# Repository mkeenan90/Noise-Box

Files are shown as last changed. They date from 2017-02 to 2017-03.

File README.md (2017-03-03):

# Noise-Box
## Summary 
I wanted to create the foundation for a noise machine to fulfill many different purposes around my house. My daughter falls asleep to the sound of lullabies; my wife and I use a fan for noise in our room. I'd like to replicate these noises with my own design.

The desired feature set is too large for the first iteration. These desired features are: bluetooth music streaming, selectable recordings of family members reading bedtime books, a daytime music box (coffee shop noise, meditation tracks, podcast player, etc.), Alexa capable, and whatever else I can think up.

In order to achieve these features, the first design focuses on just playing music from an SD card and a bunch of buttons for user input.

## Design Specification
### Software
Eagle CAD

##Schematic
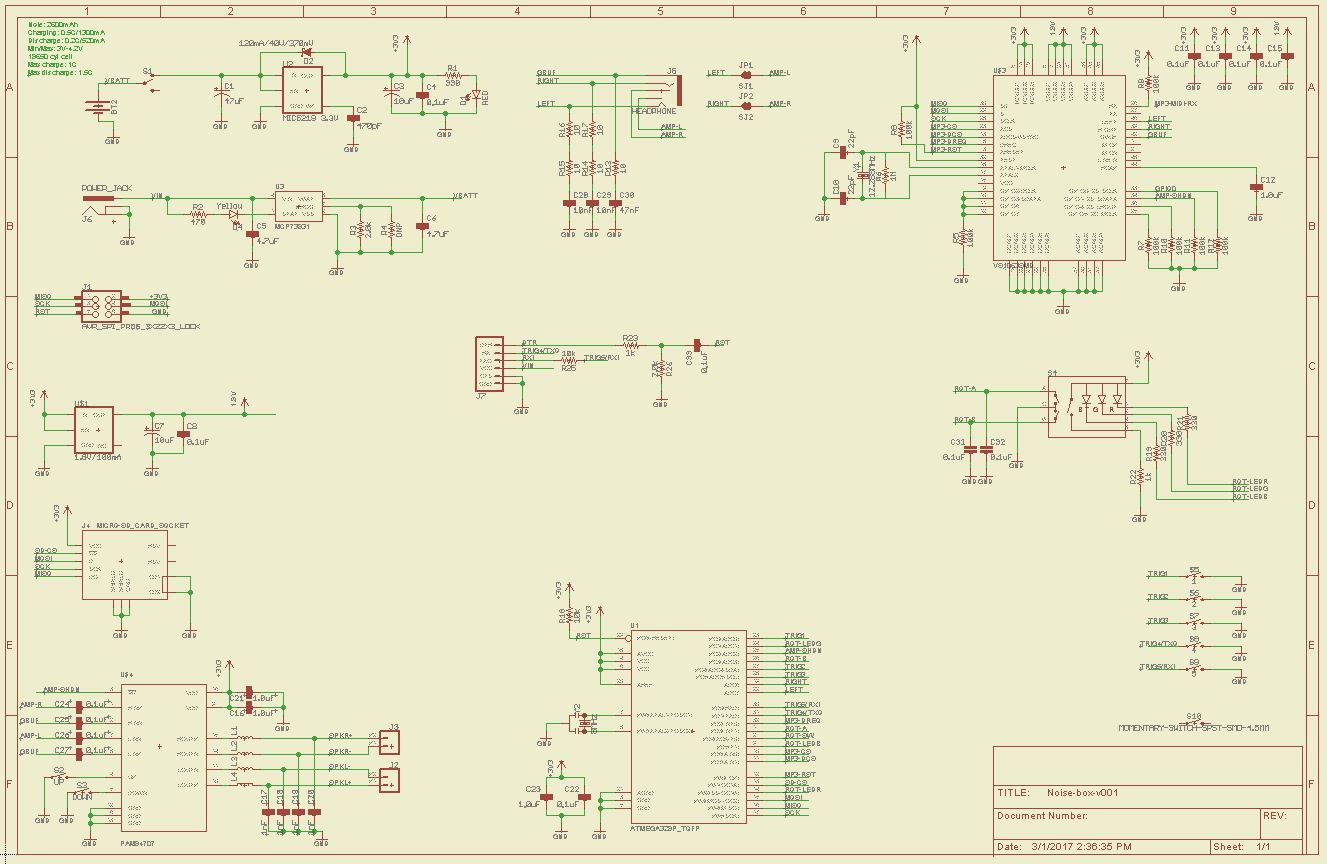
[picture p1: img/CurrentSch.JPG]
Current Schematic


##Layout
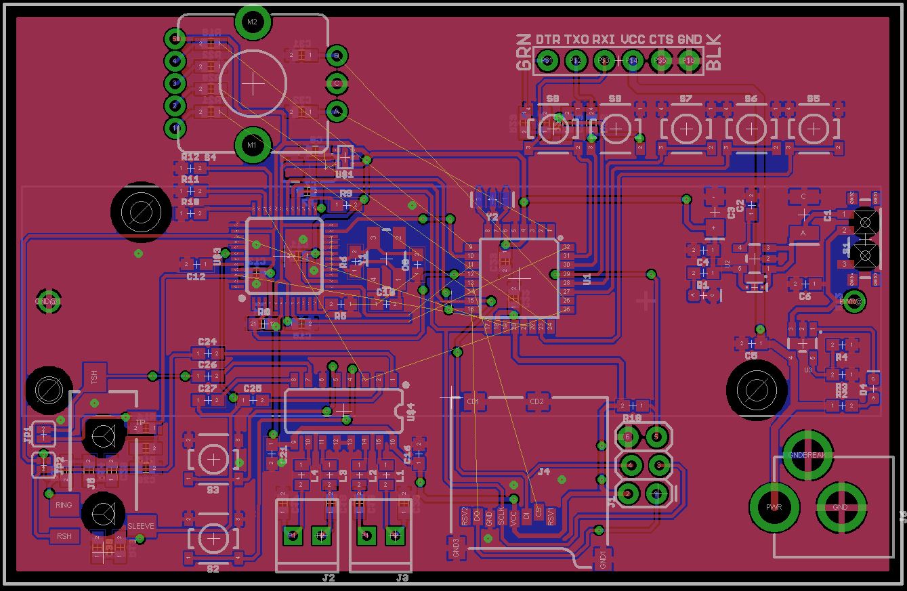
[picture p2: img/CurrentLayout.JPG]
Current Layout


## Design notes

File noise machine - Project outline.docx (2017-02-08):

Title:

Noise machine

Background Information:

There are many products available on the market to help people sleep by playing different tunes and sounds. Finding the right product with the ability to customize the music while remaining reasonably priced, proved rather difficult. My family is in need of several of these devices, with differing features for each person. Time for a custom solution.

Objective:

Create enclosed noise machine with abilities to: play lullabies, white/brown noise, background noise, meditation music, kids music, tracks of family members reading books; adjust volume; provide a user-friendly way to update music library; and survive on battery power for one night.

Minimum Features:

- Removable cord to wall outlet adapter

- Power button

- One speaker

- One music choice, plays on power-on

- Volume adjustment buttons, up and down

- Simple enclosure

Future Features:

- 10+ music tracks

- Battery powered

- Kid safe enclosure

- Removable storage

- Multiple file type support

- Bluetooth music streaming

- Android app to control music and volume

Prototype:

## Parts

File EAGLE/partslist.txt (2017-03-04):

Partlist

Exported from Noise-box-v001.brd at 3/4/2017 12:36:09 AM

EAGLE Version 6.6.0 Copyright (c) 1988-2014 CadSoft

Assembly variant: 

Part     Value                    Package                         Library                     Position (mm)         Orientation

BT2      18650                    BATTERY_18650-1043P             MAK                         (38.1 27.94)          MR0
C1       47uF                     EIA3528                         SparkFun-Capacitors         (69.723 35.687)       R270
C2       470pF                    0603                            SparkFun-Capacitors         (65.024 36.576)       R90
C3       10uF                     EIA3216                         SparkFun-Capacitors         (61.722 35.941)       R270
C4       0.1uF                    0603                            SparkFun-Capacitors         (60.706 32.512)       R180
C5       4.7uF                    0603                            SparkFun-Capacitors         (65.024 24.13)        R180
C6       4.7uF                    0603                            SparkFun-Capacitors         (69.85 29.464)        R180
C7       10uF                     EIA3216                         SparkFun-Capacitors         (24.892 39.878)       MR180
C8       0.1uF                    0603                            SparkFun-Capacitors         (25.4 42.672)         MR0
C9       22pF                     0603                            SparkFun-Capacitors         (35.052 31.242)       R90
C10      22pF                     0603                            SparkFun-Capacitors         (32.258 27.686)       R0
C11      0.1uF                    0603                            SparkFun-Capacitors         (24.384 32.004)       MR0
C12      1.0uF                    0603                            SparkFun-Capacitors         (14.986 31.75)        R180
C13      0.1uF                    0603                            SparkFun-Capacitors         (20.574 30.48)        MR0
C14      0.1uF                    0603                            SparkFun-Capacitors         (21.082 25.908)       MR0
C15      0.1uF                    0603                            SparkFun-Capacitors         (24.638 25.908)       MR180
C16      1.0uF                    0603                            SparkFun-Capacitors         (35.179 14.224)       R90
C17      1nF                      0603                            SparkFun-Capacitors         (22.987 9.779)        MR90
C18      1nF                      0603                            SparkFun-Capacitors         (27.305 9.779)        MR90
C19      1nF                      0603                            SparkFun-Capacitors         (29.845 9.779)        MR90
C20      1nF                      0603                            SparkFun-Capacitors         (33.8582 9.779)       MR90
C21      1.0uF                    0603                            SparkFun-Capacitors         (22.733 12.446)       R270
C22      0.1uF                    0603                            SparkFun-Capacitors         (46.736 21.082)       R0
C23      1.0uF                    0603                            SparkFun-Capacitors         (44.196 33.02)        MR180
C24      0.1uF                    0603                            SparkFun-Capacitors         (16.256 23.241)       R0
C25      0.1uF                    0603                            SparkFun-Capacitors         (16.256 17.018)       R0
C26      0.1uF                    0603                            SparkFun-Capacitors         (16.256 19.177)       R0
C27      0.1uF                    0603                            SparkFun-Capacitors         (16.256 21.336)       R0
C28      10nF                     0603                            SparkFun-Capacitors         (10.668 12.954)       MR180
C29      10nF                     0603                            SparkFun-Capacitors         (7.62 12.5222)        MR90
C30      47nF                     0603                            SparkFun-Capacitors         (6.35 5.334)          MR90
C31      0.1uF                    0603                            SparkFun-Capacitors         (30.7848 49.2252)     R270
C32      0.1uF                    0603                            SparkFun-Capacitors         (30.8356 45.6946)     R90
C33      0.1uF                    0603                            SparkFun-Capacitors         (48.514 43.942)       MR90
D1       RED                      LED-0603                        SparkFun-LED                (60.706 28.448)       R0
D2       120mA/40V/370mV          SOD-523                         SparkFun-DiscreteSemi       (65.278 29.21)        R0
D4       Yellow                   LED-0603                        SparkFun-LED                (75.946 20.066)       R90
J1       AVR_SPI_PROG_3X22X3_LOCK 2X3_LOCK                        SparkFun-Connectors         (56.642 10.668)       R90
J2       LEFT                     1X02_2.54_SCREWTERM             SparkFun-Connectors         (26.416 6.858)        R180
J3       RIGHT                    1X02_2.54_SCREWTERM             SparkFun-Connectors         (33.02 6.858)         R180
J4       MICRO-SD_CARD_SOCKET     MICRO-SD-SOCKET                 SparkFun-Connectors         (38.1 19.304)         R180
J5       HEADPHONE                AUDIO-JACK-3.5MM-SMD            SparkFun-Connectors         (6.858 5.334)         R90
J6       POWER_JACK               POWER_JACK_PTH                  SparkFun-Connectors         (80.772 9.398)        R90
J7       FTDI                     6_PIN_SERIAL_TARGET_SIDE_W_SILK SparkFun-Connectors         (53.086 49.53)        R0
JP1      SJ1                      SMT-JUMPER_2_NO_SILK            SparkFun-Jumpers            (7.62 24.384)         R180
JP2      SJ2                      SMT-JUMPER_2_NO_SILK            SparkFun-Jumpers            (12.4206 24.003)      R270
L1                                0805                            SparkFun-Coils              (32.258 12.319)       R270
L2                                0805                            SparkFun-Coils              (29.845 12.319)       R270
L3                                0805                            SparkFun-Coils              (27.178 12.319)       R270
L4                                0805                            SparkFun-Coils              (24.892 12.319)       R270
R1       330                      0603                            SparkFun-Resistors          (60.706 30.48)        R180
R2       470                      0603                            SparkFun-Resistors          (73.152 18.542)       R0
R3       2.0k                     0603                            SparkFun-Resistors          (73.152 21.336)       R180
R4       DNP                      0603                            SparkFun-Resistors          (73.152 24.003)       R180
R5       100k                     0603                            SparkFun-Resistors          (28.194 27.686)       R180
R6       1M                       0603                            SparkFun-Resistors          (29.464 31.496)       R90
R7       100k                     0603                            SparkFun-Resistors          (25.146 37.846)       MR180
R8       100k                     0603                            SparkFun-Resistors          (21.336 25.908)       R0
R9       100k                     0603                            SparkFun-Resistors          (28.702 36.576)       R0
R10      100k                     0603                            SparkFun-Resistors          (14.732 35.814)       R0
R11      100k                     0603                            SparkFun-Resistors          (14.732 37.846)       R0
R12      100k                     0603                            SparkFun-Resistors          (14.732 39.878)       R0
R13      10                       0603                            SparkFun-Resistors          (8.382 5.334)         MR90
R14      10                       0603                            SparkFun-Resistors          (5.588 12.4968)       MR90
R15      10                       0603                            SparkFun-Resistors          (10.668 14.732)       MR180
R16      10                       0603                            SparkFun-Resistors          (10.668 16.51)        MR0
R17      10                       0603                            SparkFun-Resistors          (3.556 12.7)          MR270
R18      10k                      0603                            SparkFun-Resistors          (54.356 18.542)       R180
R19      330                      0603                            SparkFun-Resistors          (16.51 50.292)        MR0
R20      330                      0603                            SparkFun-Resistors          (16.51 45.974)        MR0
R21      330                      0603                            SparkFun-Resistors          (16.51 43.942)        MR0
R22      1k                       0603                            SparkFun-Resistors          (16.51 48.26)         MR0
R23      1k                       0603                            SparkFun-Resistors          (44.704 43.942)       MR270
R25      10k                      0603                            SparkFun-Resistors          (50.673 43.942)       MR90
R26      2.0k                     0603                            SparkFun-Resistors          (46.482 43.942)       MR90
S1                                SWITCH_SPST_SMD_A               SparkFun-Switches           (75.184 34.036)       R270
S2       UP                       TACTILE_SWITCH_SMD_4.5MM        SparkFun-Switches           (16.764 6.604)        R180
S3       DOWN                     TACTILE_SWITCH_SMD_4.5MM        SparkFun-Switches           (16.764 13.208)       R180
S4                                ENCODER_LED_3                   SparkFun-Switches           (20.32 47.498)        R90
S5       1                        TACTILE_SWITCH_SMD_4.5MM        SparkFun-Switches           (70.612 43.434)       R0
S6       2                        TACTILE_SWITCH_SMD_4.5MM        SparkFun-Switches           (65.024 43.434)       R0
S7       3                        TACTILE_SWITCH_SMD_4.5MM        SparkFun-Switches           (59.182 43.434)       R0
S8       4                        TACTILE_SWITCH_SMD_4.5MM        SparkFun-Switches           (47.244 43.434)       R0
S9       5                        TACTILE_SWITCH_SMD_4.5MM        SparkFun-Switches           (52.832 43.434)       R0
U$1      1.8V/100mA               SC70                            SparkFun-IC-Power           (28.575 40.894)       R90
U$3      VS1063SMD                LQFP-48                         SparkFun-IC-Conversion      (23.114 32.004)       R0
U$4      PAM84707                 SO16                            RJC                         (28.448 18.034)       R180
U1       ATMEGA328P_TQFP          TQFP32-08                       SparkFun-IC-Microcontroller (44.196 29.972)       R270
U2       MIC5219 3.3V             SOT23-5                         SparkFun-IC-Power           (65.278 31.75)        R90
U3       MCP73831                 SOT23-5                         SparkFun-IC-Power           (69.596 24.13)        R180
Y1       12.288MHz                CRYSTAL-SMD-5X3.2-4PAD          SparkFun-Clocks             (32.258 31.75)        R90
Y2       8MHz                     RESONATOR-SMD-3.2X1.3           SparkFun-Clocks             (41.783 38.354)       R180

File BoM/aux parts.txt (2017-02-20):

Digikey, wall adapter, VEL05US090-US-JA, 1470-2773-ND, $6.50
Digikey, barrel connector, 694106301002, 732-5930-ND, $0.96
Digikey, battery, PRT-12895, 1568-1488-ND, $5.95
Digikey, battery holder, 1043P, 36-1043P-ND, $2.31

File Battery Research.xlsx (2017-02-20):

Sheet: Sheet1
Notes:
To simplifiy things, we will limit our battery supply to a single source - Digikey.
Search filters: NON lead-acid, in stock, active DK part, qty2 (prevent bulk pricing)
Link: http://www.digikey.com/products/en/battery-products/batteries-rechargeable-secondary/91?mnonly=0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
Steps:
1) Remove non-relevant data
2) Convert capacity to same unit for all items
Identifier | m
3) Create mAh/$ unit
4) Create Wh & Wh/$
5) Sort by Wh/$
 |  |  | Capacity standardized
 | DK PN | Capacity | # | mixed unit | mAh | Unit Price (USD) | Voltage - Rated | V (num) | Watt hours (Wh) | mAh/USD | Wh/USD | Description | Qty Avail | Battery Chemistry | Battery Cell Size | Size / Dimension | Termination Style
 | 1568-1488-ND | 2.6Ah | 2.6 | Ah | 2600 | 5.95 | 3.7V | 3.7 | 9.62 | 436.975 | 1.61681 | BATTERY LITHIUM 3.7V 2.6AH | 64 | Lithium-Ion | 18650 | 0.72" Dia x 2.56" H (18.2mm x 65.0mm) | Flat Top (Non-Extending)
 | 1568-1490-ND | 2.6Ah | 2.6 | Ah | 2600 | 6.5 | 3.7V | 3.7 | 9.62 | 400 | 1.48 | BATTERY LITHIUM 3.7V 2.6AH | 34 | Lithium-Ion | 18650 | 0.72" Dia x 2.56" H (18.2mm x 65.0mm) | Solder Tab
 | P018-ND | 3.7Ah | 3.7 | Ah | 3700 | 6.3 | 1.2V | 1.2 | 4.44 | 587.302 | 0.70476 | BATTERY NIMH 1.2V 3.7AH L-A | 412 | Nickel Metal Hydride | L-A | 0.67" Dia x 2.64" H (17.0mm x 67.0mm) | Flat Top (Non-Extending)
 | N703-ND | 2.3Ah | 2.3 | Ah | 2300 | 4.2 | 1.2V | 1.2 | 2.76 | 547.619 | 0.65714 | BATTERY NIMH 1.2V 2.3AH AA | 2646 | Nickel Metal Hydride | AA | 0.57" Dia x 1.99" H (14.5mm x 50.5mm) | Button Top (Extending)
 | P018T-ND | 3.7Ah | 3.7 | Ah | 3700 | 6.97 | 1.2V | 1.2 | 4.44 | 530.846 | 0.63702 | BATTERY NIMH 1.2V 3.7AH L-A | 0 | Nickel Metal Hydride | L-A | - | Solder Tab
 | P220-ND | 2Ah | 2 | Ah | 2000 | 3.98 | 1.2V | 1.2 | 2.4 | 502.513 | 0.60302 | BATTERY NIMH 1.2V 2AH AA | 19004 | Nickel Metal Hydride | AA | 0.57" Dia x 1.99" H (14.5mm x 50.5mm) | Button Top (Extending)
 | P690-ND | 2.45Ah | 2.45 | Ah | 2450 | 5.25 | 1.2V | 1.2 | 2.94 | 466.667 | 0.56 | BATTERY NIMH 1.2V 2.45AH A | 677 | Nickel Metal Hydride | A | 0.67" Dia x 1.97" H (17.0mm x 50.0mm) | Flat Top (Non-Extending)
 | N703T-ND | 2.3Ah | 2.3 | Ah | 2300 | 5.07 | 1.2V | 1.2 | 2.76 | 453.649 | 0.54438 | BATTERY NIMH 1.2V 2.3AH AA | 0 | Nickel Metal Hydride | AA | - | Solder Tab
 | SY156-ND | 1.8Ah | 1.8 | Ah | 1800 | 3.98 | 1.2V | 1.2 | 2.16 | 452.261 | 0.54271 | BATTERY NICAD 1.2V 1.8AH SC | 3170 | Nickel Cadmium | SC | 0.87" Dia x 1.67" H (22.2mm x 42.3mm) | Button Top (Extending)
 | P688-ND | 1.9Ah | 1.9 | Ah | 1900 | 4.25 | 1.2V | 1.2 | 2.28 | 447.059 | 0.53647 | BATTERY NIMH 1.2V 1.9AH AA | 1022 | Nickel Metal Hydride | AA | 0.57" Dia x 1.99" H (14.5mm x 50.5mm) | Button Top (Extending)
 | SY144-ND | 1.5Ah | 1.5 | Ah | 1500 | 3.4 | 1.2V | 1.2 | 1.8 | 441.176 | 0.52941 | BATTERY NIMH 1.2V 1.5AH AA | 2748 | Nickel Metal Hydride | AA | 0.56" Dia x 1.97" H (14.2mm x 50.0mm) | Flat Top (Non-Extending)
 | P015-ND | 1.5Ah | 1.5 | Ah | 1500 | 3.43 | 1.2V | 1.2 | 1.8 | 437.318 | 0.52478 | BATTERY NIMH 1.2V 1.5AH AA | 11170 | Nickel Metal Hydride | AA | 0.57" Dia x 1.99" H (14.5mm x 50.5mm) | Flat Top (Non-Extending)
 | P017-ND | 2.1Ah | 2.1 | Ah | 2100 | 4.88 | 1.2V | 1.2 | 2.52 | 430.328 | 0.51639 | BATTERY NIMH 1.2V 2.1AH A | 2536 | Nickel Metal Hydride | A | 0.67" Dia x 1.97" H (17.0mm x 50.0mm) | Flat Top (Non-Extending)
 | P220T-ND | 2Ah | 2 | Ah | 2000 | 4.65 | 1.2V | 1.2 | 2.4 | 430.108 | 0.51613 | BATTERY NIMH 1.2V 2AH AA | 7 | Nickel Metal Hydride | AA | 0.57" Dia x 1.99" H (14.5mm x 50.5mm) | Solder Tab
 | SY146-ND | 2.45Ah | 2.45 | Ah | 2450 | 5.93 | 1.2V | 1.2 | 2.94 | 413.153 | 0.49578 | BATTERY NIMH 1.2V 2.45AH A | 3333 | Nickel Metal Hydride | A | 0.67" Dia x 1.97" H (17.0mm x 50.0mm) | Flat Top (Non-Extending)
 | SY610-ND | 1.9Ah | 1.9 | Ah | 1900 | 4.75 | 1.2V | 1.2 | 2.28 | 400 | 0.48 | BATTERY NIMH 1.2V 1.9AH AA | 553 | Nickel Metal Hydride | AA | 0.56" Dia x 1.98" H (14.2mm x 50.4mm) | Button Top (Extending)
 | SY635-ND | 2.4Ah | 2.4 | Ah | 2400 | 6.13 | 1.2V | 1.2 | 2.88 | 391.517 | 0.46982 | BATTERY NIMH 1.2V 2.4AH AA | 1394 | Nickel Metal Hydride | AA | 0.56" Dia x 1.98" H (14.2mm x 50.4mm) | Button Top (Extending)
 | SY134-ND | 2.3Ah | 2.3 | Ah | 2300 | 6 | 1.2V | 1.2 | 2.76 | 383.333 | 0.46 | BATTERY NIMH 1.2V 2.3AH AA | 2282 | Nickel Metal Hydride | AA | 0.57" Dia x 1.98" H (14.4mm x 50.4mm) | Button Top (Extending)
 | SY123-ND | 3Ah | 3 | Ah | 3000 | 7.85 | 1.2V | 1.2 | 3.6 | 382.166 | 0.4586 | BATTERY NICAD 1.2V 3AH C | 1112 | Nickel Cadmium | C | 1.00" Dia x 1.94" H (25.3mm x 49.3mm) | Button Top (Extending)
 | P017T-ND | 2.1Ah | 2.1 | Ah | 2100 | 5.55 | 1.2V | 1.2 | 2.52 | 378.378 | 0.45405 | BATTERY NIMH 1.2V 2.1AH A | 15 | Nickel Metal Hydride | A | - | Solder Tab
 | SY114-ND | 700mAh | 700 | mAh | 700 | 1.88 | 1.2V | 1.2 | 0.84 | 372.34 | 0.44681 | BATTERY NICAD 1.2V 700MAH AA | 23516 | Nickel Cadmium | AA | 0.55" Dia x 1.96" H (14.0mm x 49.8mm) | Button Top, Wide (Extending)
 | SY146T-ND | 2.45Ah | 2.45 | Ah | 2450 | 6.6 | 1.2V | 1.2 | 2.94 | 371.212 | 0.44545 | BATTERY NIMH 1.2V 2.45AH A | 0 | Nickel Metal Hydride | A | - | Solder Tab
 | SY144T-ND | 1.5Ah | 1.5 | Ah | 1500 | 4.07 | 1.2V | 1.2 | 1.8 | 368.55 | 0.44226 | BATTERY NIMH 1.2V 1.5AH AA | 3 | Nickel Metal Hydride | AA | - | Solder Tab
 | P688T-ND | 1.9Ah | 1.9 | Ah | 1900 | 5.17 | 1.2V | 1.2 | 2.28 | 367.505 | 0.44101 | BATTERY NIMH 1.2V 1.9AH AA | 0 | Nickel Metal Hydride | AA | - | Solder Tab
 | P015T-ND | 1.5Ah | 1.5 | Ah | 1500 | 4.1 | 1.2V | 1.2 | 1.8 | 365.854 | 0.43902 | BATTERY NIMH 1.2V 1.5AH AA | 36 | Nickel Metal Hydride | AA | - | Solder Tab
 | SY139-ND | 1.95Ah | 1.95 | Ah | 1950 | 5.35 | 1.2V | 1.2 | 2.34 | 364.486 | 0.43738 | BATTERY NIMH 1.2V 1.95AH 4/5 A | 813 | Nickel Metal Hydride | 4/5 A | 0.67" Dia x 1.69" H (17.0mm x 43.0mm) | Flat Top (Non-Extending)
 | SY121-ND | 1.7Ah | 1.7 | Ah | 1700 | 4.75 | 1.2V | 1.2 | 2.04 | 357.895 | 0.42947 | BATTERY NICAD 1.2V 1.7AH SC | 2215 | Nickel Cadmium | SC | 0.88" Dia x 1.67" H (22.3mm x 42.3mm) | Button Top (Extending)
 | SY610T-ND | 1.9Ah | 1.9 | Ah | 1900 | 5.42 | 1.2V | 1.2 | 2.28 | 350.554 | 0.42066 | BATTERY NIMH 1.2V 1.9AH AA | 0 | Nickel Metal Hydride | AA | - | Solder Tab
 | P010T-ND | 2Ah | 2 | Ah | 2000 | 5.77 | 1.2V | 1.2 | 2.4 | 346.62 | 0.41594 | BATTERY NIMH 1.2V 2AH 4/5 A | 13 | Nickel Metal Hydride | 4/5 A | - | Solder Tab
 | SY134T-ND | 2.3Ah | 2.3 | Ah | 2300 | 6.67 | 1.2V | 1.2 | 2.76 | 344.828 | 0.41379 | BATTERY NIMH 1.2V 2.3AH AA | 20 | Nickel Metal Hydride | AA | - | Solder Tab
 | P013-ND | 1.15Ah | 1.15 | Ah | 1150 | 3.35 | 1.2V | 1.2 | 1.38 | 343.284 | 0.41194 | BATTERY NIMH 1.2V 1.15AH 4/5 AA | 978 | Nickel Metal Hydride | 4/5 AA | 0.57" Dia x 1.69" H (14.5mm x 43.0mm) | Flat Top (Non-Extending)
 | SY115-ND | 700mAh | 700 | mAh | 700 | 2.05 | 1.2V | 1.2 | 0.84 | 341.463 | 0.40976 | BATTERY NICAD 1.2V 700MAH AA | 2208 | Nickel Cadmium | AA | 0.55" Dia x 1.91" H (14.0mm x 48.5mm) | Button Top, Wide (Extending)
 | SY156T-ND | 1.8Ah | 1.8 | Ah | 1800 | 5.45 | 1.2V | 1.2 | 2.16 | 330.275 | 0.39633 | BATTERY NICAD 1.2V 1.8AH SC | 12 | Nickel Cadmium | SC | - | Solder Tab
 | SY139T-ND | 1.95Ah | 1.95 | Ah | 1950 | 6.02 | 1.2V | 1.2 | 2.34 | 323.92 | 0.3887 | BATTERY NIMH 1.2V 1.95AH 4/5 A | 414 | Nickel Metal Hydride | 4/5 A | - | Solder Tab
 | SY120-ND | 1.3Ah | 1.3 | Ah | 1300 | 4.23 | 1.2V | 1.2 | 1.56 | 307.329 | 0.36879 | BATTERY NICAD 1.2V 1.3AH SC | 217 | Nickel Cadmium | SC | 0.88" Dia x 1.67" H (22.3mm x 42.3mm) | Button Top (Extending)
 | P013T-ND | 1.15Ah | 1.15 | Ah | 1150 | 4.02 | 1.2V | 1.2 | 1.38 | 286.07 | 0.34328 | BATTERY NIMH 1.2V 1.15AH 4/5 AA | 26 | Nickel Metal Hydride | 4/5 AA | - | Solder Tab
 | SY153-ND | 930mAh | 930 | mAh | 930 | 3.28 | 1.2V | 1.2 | 1.116 | 283.537 | 0.34024 | BATTERY NIMH 1.2V 930MAH AAA | 8572 | Nickel Metal Hydride | AAA | 0.41" Dia x 1.75" H (10.5mm x 44.5mm) | Button Top (Extending)
 | SY118-ND | 1.2Ah | 1.2 | Ah | 1200 | 4.25 | 1.2V | 1.2 | 1.44 | 282.353 | 0.33882 | BATTERY NICAD 1.2V 1.2AH 4/5 SC | 4596 | Nickel Cadmium | 4/5 SC | 0.88" Dia x 1.31" H (22.3mm x 33.3mm) | Button Top (Extending)
 | SY121T-ND | 1.7Ah | 1.7 | Ah | 1700 | 6.38 | 1.2V | 1.2 | 2.04 | 266.458 | 0.31975 | BATTERY NICAD 1.2V 1.7AH SC | 7 | Nickel Cadmium | SC | - | Solder Tab
 | 1568-1493-ND | 400mAh | 400 | mAh | 400 | 4.95 | 3.7V | 3.7 | 1.48 | 80.808 | 0.29899 | BATTERY LITHIUM 3.7V 400MAH | 35 | Lithium-Ion | - | 1.04" L x 1.45" W x 0.20" H (26.5mm x 36.9mm x 5.0mm) | Wire Leads with Connector
 | SY114T-ND | 700mAh | 700 | mAh | 700 | 2.93 | 1.2V | 1.2 | 0.84 | 238.908 | 0.28669 | BATTERY NICAD 1.2V 700MAH AA | 0 | Nickel Cadmium | AA | - | Solder Tab
 | P008-ND | 700mAh | 700 | mAh | 700 | 2.95 | 1.2V | 1.2 | 0.84 | 237.288 | 0.28475 | BATTERY NIMH 1.2V 700MAH AAA | 131026 | Nickel Metal Hydride | AAA | 0.41" Dia x 1.75" H (10.5mm x 44.5mm) | Button Top (Extending)
 | P689-ND | 750mAh | 750 | mAh | 750 | 3.2 | 1.2V | 1.2 | 0.9 | 234.375 | 0.28125 | BATTERY NIMH 1.2V 750MAH AAA | 4515 | Nickel Metal Hydride | AAA | 0.41" Dia x 1.75" H (10.5mm x 44.5mm) | Button Top (Extending)
 | SY612-ND | 950mAh | 950 | mAh | 950 | 4.2 | 1.2V | 1.2 | 1.14 | 226.19 | 0.27143 | BATTERY NIMH 1.2V 950MAH AA | 860 | Nickel Metal Hydride | AA | 0.56" Dia x 1.97" H (14.2mm x 50.0mm) | Button Top, Wide (Extending)
 | SY120T-ND | 1.3Ah | 1.3 | Ah | 1300 | 5.75 | 1.2V | 1.2 | 1.56 | 226.087 | 0.2713 | BATTERY NICAD 1.2V 1.3AH SC | 1 | Nickel Cadmium | SC | - | Solder Tab
 | SY143-ND | 650mAh | 650 | mAh | 650 | 2.9 | 1.2V | 1.2 | 0.78 | 224.138 | 0.26897 | BATTERY NIMH 1.2V 650MAH AAA | 902 | Nickel Metal Hydride | AAA | 0.41" Dia x 1.75" H (10.5mm x 44.5mm) | Flat Top (Non-Extending)
 | SY115T-ND | 700mAh | 700 | mAh | 700 | 3.14 | 1.2V | 1.2 | 0.84 | 222.93 | 0.26752 | BATTERY NICAD 1.2V 700MAH AA | 34 | Nickel Cadmium | AA | - | Solder Tab
 | SY118T-ND | 1.2Ah | 1.2 | Ah | 1200 | 5.78 | 1.2V | 1.2 | 1.44 | 207.612 | 0.24913 | BATTERY NICAD 1.2V 1.2AH 4/5 SC | 0 | Nickel Cadmium | 4/5 SC | - | Solder Tab
 | P213T-ND | 700mAh | 700 | mAh | 700 | 3.42 | 1.2V | 1.2 | 0.84 | 204.678 | 0.24561 | BATTERY NIMH 1.2V 700MAH AAA | 37 | Nickel Metal Hydride | AAA | - | Solder Tab
 | SY612T-ND | 950mAh | 950 | mAh | 950 | 4.87 | 1.2V | 1.2 | 1.14 | 195.072 | 0.23409 | BATTERY NIMH 1.2V 950MAH AA | 0 | Nickel Metal Hydride | AA | - | Solder Tab
 | P008T-ND | 700mAh | 700 | mAh | 700 | 3.62 | 1.2V | 1.2 | 0.84 | 193.37 | 0.23204 | BATTERY NIMH 1.2V 700MAH AAA | 61 | Nickel Metal Hydride | AAA | - | Solder Tab
 | SY143T-ND | 650mAh | 650 | mAh | 650 | 3.57 | 1.2V | 1.2 | 0.78 | 182.073 | 0.21849 | BATTERY NIMH 1.2V 650MAH AAA | 30 | Nickel Metal Hydride | AAA | - | Solder Tab
 | P634-ND | 500mAh | 500 | mAh | 500 | 2.85 | 1.2V | 1.2 | 0.6 | 175.439 | 0.21053 | BATTERY NIMH 1.2V 500MAH AAA | 5410 | Nickel Metal Hydride | AAA | 0.41" Dia x 1.75" H (10.5mm x 44.5mm) | Flat Top (Non-Extending)
 | SY142T-ND | 760mAh | 760 | mAh | 760 | 4.42 | 1.2V | 1.2 | 0.912 | 171.946 | 0.20633 | BATTERY NIMH 1.2V 760MAH 5/4 AAA | 0 | Nickel Metal Hydride | 5/4 AAA | - | Solder Tab
 | 1528-1858-ND | 350mAh | 350 | mAh | 350 | 6.95 | 3.7V | 3.7 | 1.295 | 50.36 | 0.18633 | BATTERY LITHIUM 3.7V 350MAH | 48 | Lithium-Ion | - | 1.42" L x 0.79" W x 0.22" H (36.0mm x 20.0mm x 5.6mm) | Wire Leads with Connector
 | P634T-ND | 500mAh | 500 | mAh | 500 | 3.52 | 1.2V | 1.2 | 0.6 | 142.045 | 0.17045 | BATTERY NIMH 1.2V 500MAH AAA | 50 | Nickel Metal Hydride | AAA | - | Solder Tab
 | 1528-1839-ND | 150mAh | 150 | mAh | 150 | 5.95 | 3.7V | 3.7 | 0.555 | 25.21 | 0.09328 | BATTERY LITHIUM 3.7V 150MAH | 44 | Lithium-Ion | - | 0.78" L x 1.02" W x 0.15" H (19.8mm x 26.0mm x 3.8mm) | Wire Leads with Connector
 | 1568-1491-ND | 110mAh | 110 | mAh | 110 | 4.95 | 3.7V | 3.7 | 0.407 | 22.222 | 0.08222 | BATTERY LITHIUM 3.7V 110MAH | 51 | Lithium-Ion | - | 0.98" L x 0.59" W x 0.16" H (25.0mm x 15.0mm x 4.0mm) | Wire Leads with Connector
 | SY616-ND | 100mAh | 100 | mAh | 100 | 3.82 | 3V | 3 | 0.3 | 26.178 | 0.07853 | BATT LITH 3V 100MAH COIN 24.5MM | 9423 | Lithium | Coin, 24.5mm | 0.96" Dia x 0.12" H (24.5mm x 3.0mm) | PC Pin (Horizontal Mount)
 | 1528-1837-ND | 100mAh | 100 | mAh | 100 | 5.95 | 3.7V | 3.7 | 0.37 | 16.807 | 0.06218 | BATTERY LITHIUM 3.7V 100MAH | 41 | Lithium-Ion | - | 0.45" L x 1.22" W x 0.15" H (11.5mm x 31.0mm x 3.8mm) | Wire Leads with Connector
 | SY615-ND | 100mAh | 100 | mAh | 100 | 4.83 | 3V | 3 | 0.3 | 20.704 | 0.06211 | BATT LITH 3V 100MAH COIN 24.5MM | 4980 | Lithium | Coin, 24.5mm | 0.96" Dia x 0.12" H (24.5mm x 3.0mm) | Wire Leads with Connector
 | 1568-1489-ND | 110mAh | 110 | mAh | 110 | 6.95 | 3.7V | 3.7 | 0.407 | 15.827 | 0.05856 | BATTERY LITHIUM 3.7V 110MAH | 22 | Lithium-Ion | - | 1.10" L x 0.47" W x 0.22" H (28.0mm x 12.0mm x 5.7mm) | Wire Leads with Connector
 | P047-ND | 45mAh | 45 | mAh | 45 | 2.71 | 3V | 3 | 0.135 | 16.605 | 0.04982 | BATT LITH 3V 45MAH COIN 20.0MM | 53864 | Lithium | Coin, 20.0mm | 0.79" Dia x 0.08" H (20.0mm x 2.0mm) | PC Pin (Horizontal Mount)
 | P045-ND | 45mAh | 45 | mAh | 45 | 2.71 | 3V | 3 | 0.135 | 16.605 | 0.04982 | BATT LITH 3V 45MAH COIN 20.0MM | 4151 | Lithium | Coin, 20.0mm | 0.79" Dia x 0.08" H (20.0mm x 2.0mm) | PC Pin (Vertical Mount)
 | P046-ND | 45mAh | 45 | mAh | 45 | 2.71 | 3V | 3 | 0.135 | 16.605 | 0.04982 | BATT LITH 3V 45MAH COIN 20.0MM | 1292 | Lithium | Coin, 20.0mm | 0.79" Dia x 0.08" H (20.0mm x 2.0mm) | PC Pin (Vertical Mount)
 | P664-ND | 45mAh | 45 | mAh | 45 | 3.39 | 3V | 3 | 0.135 | 13.274 | 0.03982 | BATT LITH 3V 45MAH COIN 20.0MM | 26971 | Lithium | Coin, 20.0mm | 0.79" Dia x 0.08" H (20.0mm x 2.0mm) | SMD (SMT) Tab
 | 1568-1496-ND | 40mAh | 40 | mAh | 40 | 4.5 | 3.7V | 3.7 | 0.148 | 8.889 | 0.03289 | BATTERY LITHIUM 3.7V 40MAH | 41 | Lithium-Ion | - | 0.79" L x 0.43" W x 0.12" H (20.0mm x 11.0mm x 3.0mm) | Wire Leads with Connector
 | P295-ND | 17mAh | 17 | mAh | 17 | 2.39 | 3V | 3 | 0.051 | 7.113 | 0.02134 | BATT LITH 3V 17MAH COIN 12.5MM | 67416 | Lithium | Coin, 12.5mm | 0.49" Dia x 0.08" H (12.5mm x 2.0mm) | SMD (SMT) Tab
 | P294-ND | 17mAh | 17 | mAh | 17 | 2.39 | 3V | 3 | 0.051 | 7.113 | 0.02134 | BATT LITH 3V 17MAH COIN 12.5MM | 10971 | Lithium | Coin, 12.5mm | 0.49" Dia x 0.08" H (12.5mm x 2.0mm) | PC Pin (Vertical Mount)
 | P663-ND | 17mAh | 17 | mAh | 17 | 2.39 | 3V | 3 | 0.051 | 7.113 | 0.02134 | BATT LITH 3V 17MAH COIN 12.5MM | 10694 | Lithium | Coin, 12.5mm | 0.49" Dia x 0.08" H (12.5mm x 2.0mm) | PC Pin (Vertical Mount)
 | P002-ND | 50mAh | 50 | mAh | 50 | 7.45 | 3V | 3 | 0.15 | 6.711 | 0.02013 | BATT LITH 3V 50MAH COIN 23.0MM | 1755 | Lithium | Coin, 23.0mm | 0.91" Dia x 0.12" H (23.0mm x 3.0mm) | SMD (SMT) Tab
 | P085-ND | 50mAh | 50 | mAh | 50 | 7.45 | 3V | 3 | 0.15 | 6.711 | 0.02013 | BATT LITH 3V 50MAH COIN 23.0MM | 1083 | Lithium | Coin, 23.0mm | 0.91" Dia x 0.12" H (23.0mm x 3.0mm) | PC Pin (Horizontal Mount)
 | P086-ND | 50mAh | 50 | mAh | 50 | 7.45 | 3V | 3 | 0.15 | 6.711 | 0.02013 | BATT LITH 3V 50MAH COIN 23.0MM | 111 | Lithium | Coin, 23.0mm | 0.91" Dia x 0.12" H (23.0mm x 3.0mm) | PC Pin (Vertical Mount)
 | VL-2330/G1CN-ND | 50mAh | 50 | mAh | 50 | 7.45 | 3V | 3 | 0.15 | 6.711 | 0.02013 | BATT LITH 3V 50MAH COIN 23.0MM | 1655 | Lithium | Coin, 23.0mm | 0.91" Dia x 0.12" H (23.0mm x 3.0mm) | PC Pin (Vertical Mount)
 | P083-ND | 30mAh | 30 | mAh | 30 | 5.94 | 3V | 3 | 0.09 | 5.051 | 0.01515 | BATT LITH 3V 30MAH COIN 23.0MM | 5096 | Lithium | Coin, 23.0mm | 0.91" Dia x 0.08" H (23.0mm x 2.0mm) | PC Pin (Horizontal Mount)
 | P084-ND | 30mAh | 30 | mAh | 30 | 5.94 | 3V | 3 | 0.09 | 5.051 | 0.01515 | BATT LITH 3V 30MAH COIN 23.0MM | 699 | Lithium | Coin, 23.0mm | 0.91" Dia x 0.08" H (23.0mm x 2.0mm) | PC Pin (Vertical Mount)
 | P221-ND | 30mAh | 30 | mAh | 30 | 5.94 | 3V | 3 | 0.09 | 5.051 | 0.01515 | BATT LITH 3V 30MAH COIN 23.0MM | 611 | Lithium | Coin, 23.0mm | 0.91" Dia x 0.08" H (23.0mm x 2.0mm) | SMD (SMT) Tab
 | P296-ND | 11mAh | 11 | mAh | 11 | 2.28 | 3V | 3 | 0.033 | 4.825 | 0.01447 | BATTERY LITH 3V 11MAH COIN 9.5MM | 3329 | Lithium | Coin, 9.5mm | 0.37" Dia x 0.08" H (9.5mm x 2.1mm) | SMD (SMT) Tab
 | 728-1058-ND | 11mAh | 11 | mAh | 11 | 2.41 | 3V | 3 | 0.033 | 4.564 | 0.01369 | BATTERY LITH 3V 11MAH COIN 9.5MM | 17191 | Lithium | Coin, 9.5mm | 0.37" Dia x 0.08" H (9.5mm x 2.1mm) | SMD (SMT) Tab
 | P081-ND | 20mAh | 20 | mAh | 20 | 4.8 | 3V | 3 | 0.06 | 4.167 | 0.0125 | BATT LITH 3V 20MAH COIN 20.0MM | 4190 | Lithium | Coin, 20.0mm | 0.79" Dia x 0.08" H (20.0mm x 2.0mm) | PC Pin (Horizontal Mount)
 | P082-ND | 20mAh | 20 | mAh | 20 | 4.8 | 3V | 3 | 0.06 | 4.167 | 0.0125 | BATT LITH 3V 20MAH COIN 20.0MM | 1386 | Lithium | Coin, 20.0mm | 0.79" Dia x 0.08" H (20.0mm x 2.0mm) | PC Pin (Vertical Mount)
 | P007-ND | 5mAh | 5 | mAh | 5 | 1.8 | 3V | 3 | 0.015 | 2.778 | 0.00833 | BATTERY LITH 3V 5MAH COIN 6.8MM | 19278 | Lithium | Coin, 6.8mm | 0.27" Dia x 0.09" H (6.8mm x 2.2mm) | Requires Holder
 | 728-1057-ND | 5.5mAh | 5.5 | mAh | 5.5 | 2.04 | 3V | 3 | 0.0165 | 2.696 | 0.00809 | BATT LITH 3V 5.5MAH COIN 6.8MM | 66945 | Lithium | Coin, 6.8mm | 0.27" Dia x 0.08" H (6.8mm x 2.1mm) | SMD (SMT) Tab
 | SY103-ND | 5.8mAh | 5.8 | mAh | 5.8 | 2.25 | 3V | 3 | 0.0174 | 2.578 | 0.00773 | BATT LITH 3V 5.8MAH COIN 6.8MM | 16331 | Lithium | Coin, 6.8mm | 0.27" Dia x 0.09" H (6.8mm x 2.2mm) | SMD (SMT) Tab
 | P044-ND | 5mAh | 5 | mAh | 5 | 1.99 | 3V | 3 | 0.015 | 2.513 | 0.00754 | BATTERY LITH 3V 5MAH COIN 6.8MM | 229092 | Lithium | Coin, 6.8mm | 0.27" Dia x 0.09" H (6.8mm x 2.2mm) | SMD (SMT) Tab
 | 728-1079-ND | 6.5mAh | 6.5 | mAh | 6.5 | 3.08 | 3V | 3 | 0.0195 | 2.11 | 0.00633 | BATT LITH 3V 6.5MAH COIN 9.5MM | 967 | Lithium | Coin, 9.5mm | 0.37" Dia x 0.08" H (9.5mm x 2.1mm) | Requires Holder
 | 728-1077-ND | 6.5mAh | 6.5 | mAh | 6.5 | 3.21 | 3V | 3 | 0.0195 | 2.025 | 0.00607 | BATT LITH 3V 6.5MAH COIN 9.5MM | 803 | Lithium | Coin, 9.5mm | 0.37" Dia x 0.08" H (9.5mm x 2.1mm) | SMD (SMT) Tab
 | P297-ND | 3.4mAh | 3.4 | mAh | 3.4 | 2.04 | 3V | 3 | 0.0102 | 1.667 | 0.005 | BATT LITH 3V 3.4MAH COIN 6.8MM | 4248 | Lithium | Coin, 6.8mm | 0.27" Dia x 0.06" H (6.8mm x 1.5mm) | SMD (SMT) Tab
 | 728-1054-ND | 3.4mAh | 3.4 | mAh | 3.4 | 2.04 | 3V | 3 | 0.0102 | 1.667 | 0.005 | BATT LITH 3V 3.4MAH COIN 5.8MM | 3442 | Lithium | Coin, 5.8mm | 0.23" Dia x 0.07" H (5.8mm x 1.8mm) | SMD (SMT) Tab
 | 728-1055-ND | 3.4mAh | 3.4 | mAh | 3.4 | 2.1 | 3V | 3 | 0.0102 | 1.619 | 0.00486 | BATT LITH 3V 3.4MAH COIN 6.8MM | 12966 | Lithium | Coin, 6.8mm | 0.27" Dia x 0.06" H (6.8mm x 1.4mm) | SMD (SMT) Tab
 | P080-ND | 7mAh | 7 | mAh | 7 | 4.51 | 3V | 3 | 0.021 | 1.552 | 0.00466 | BATTERY LITH 3V 7MAH COIN 12.5MM | 5310 | Lithium | Coin, 12.5mm | 0.49" Dia x 0.08" H (12.5mm x 2.0mm) | PC Pin (Vertical Mount)
 | P079-ND | 7mAh | 7 | mAh | 7 | 4.51 | 3V | 3 | 0.021 | 1.552 | 0.00466 | BATTERY LITH 3V 7MAH COIN 12.5MM | 5278 | Lithium | Coin, 12.5mm | 0.49" Dia x 0.08" H (12.5mm x 2.0mm) | PC Pin (Horizontal Mount)
 | P665-ND | 7mAh | 7 | mAh | 7 | 4.51 | 3V | 3 | 0.021 | 1.552 | 0.00466 | BATTERY LITH 3V 7MAH COIN 12.5MM | 4532 | Lithium | Coin, 12.5mm | 0.49" Dia x 0.08" H (12.5mm x 2.0mm) | SMD (SMT) Tab
 | SY152-ND | 3.4mAh | 3.4 | mAh | 3.4 | 2.25 | 3V | 3 | 0.0102 | 1.511 | 0.00453 | BATT LITH 3V 3.4MAH COIN 6.8MM | 15173 | Lithium | Coin, 6.8mm | 0.27" Dia x 0.06" H (6.8mm x 1.4mm) | SMD (SMT) Tab
 | 728-1078-ND | 3mAh | 3 | mAh | 3 | 2.55 | 3V | 3 | 0.009 | 1.176 | 0.00353 | BATTERY LITH 3V 3MAH COIN 6.8MM | 2000 | Lithium | Coin, 6.8mm | 0.27" Dia x 0.08" H (6.8mm x 2.1mm) | Requires Holder
 | 728-1080-ND | 3mAh | 3 | mAh | 3 | 2.81 | 3V | 3 | 0.009 | 1.068 | 0.0032 | BATTERY LITH 3V 3MAH COIN 6.8MM | 1436 | Lithium | Coin, 6.8mm | 0.27" Dia x 0.08" H (6.8mm x 2.1mm) | SMD (SMT) Tab
 | 728-1081-ND | 5.5mAh | 5.5 | mAh | 5.5 | 3.08 | 1.5V | 1.5 | 0.00825 | 1.786 | 0.00268 | BATT LITH 1.5V 5.5MAH COIN 9.5MM | 998 | Lithium | Coin, 9.5mm | 0.37" Dia x 0.08" H (9.5mm x 2.1mm) | Requires Holder
 | 728-1082-ND | 5.5mAh | 5.5 | mAh | 5.5 | 3.34 | 1.5V | 1.5 | 0.00825 | 1.647 | 0.00247 | BATT LITH 1.5V 5.5MAH COIN 9.5MM | 888 | Lithium | Coin, 9.5mm | 0.37" Dia x 0.08" H (9.5mm x 2.1mm) | SMD (SMT) Tab
 | 728-1053-ND | 1mAh | 1 | mAh | 1 | 1.88 | 3V | 3 | 0.003 | 0.532 | 0.0016 | BATTERY LITH 3V 1MAH COIN 4.8MM | 7911 | Lithium | Coin, 4.8mm | 0.19" Dia x 0.05" H (4.8mm x 1.2mm) | SMD (SMT) Tab
 | P048-ND | 1.5mAh | 1.5 | mAh | 1.5 | 4.48 | 3V | 3 | 0.0045 | 0.335 | 0.001 | BATT LITH 3V 1.5MAH COIN 6.8MM | 2085 | Lithium | Coin, 6.8mm | 0.27" Dia x 0.09" H (6.8mm x 2.2mm) | SMD (SMT) Tab
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

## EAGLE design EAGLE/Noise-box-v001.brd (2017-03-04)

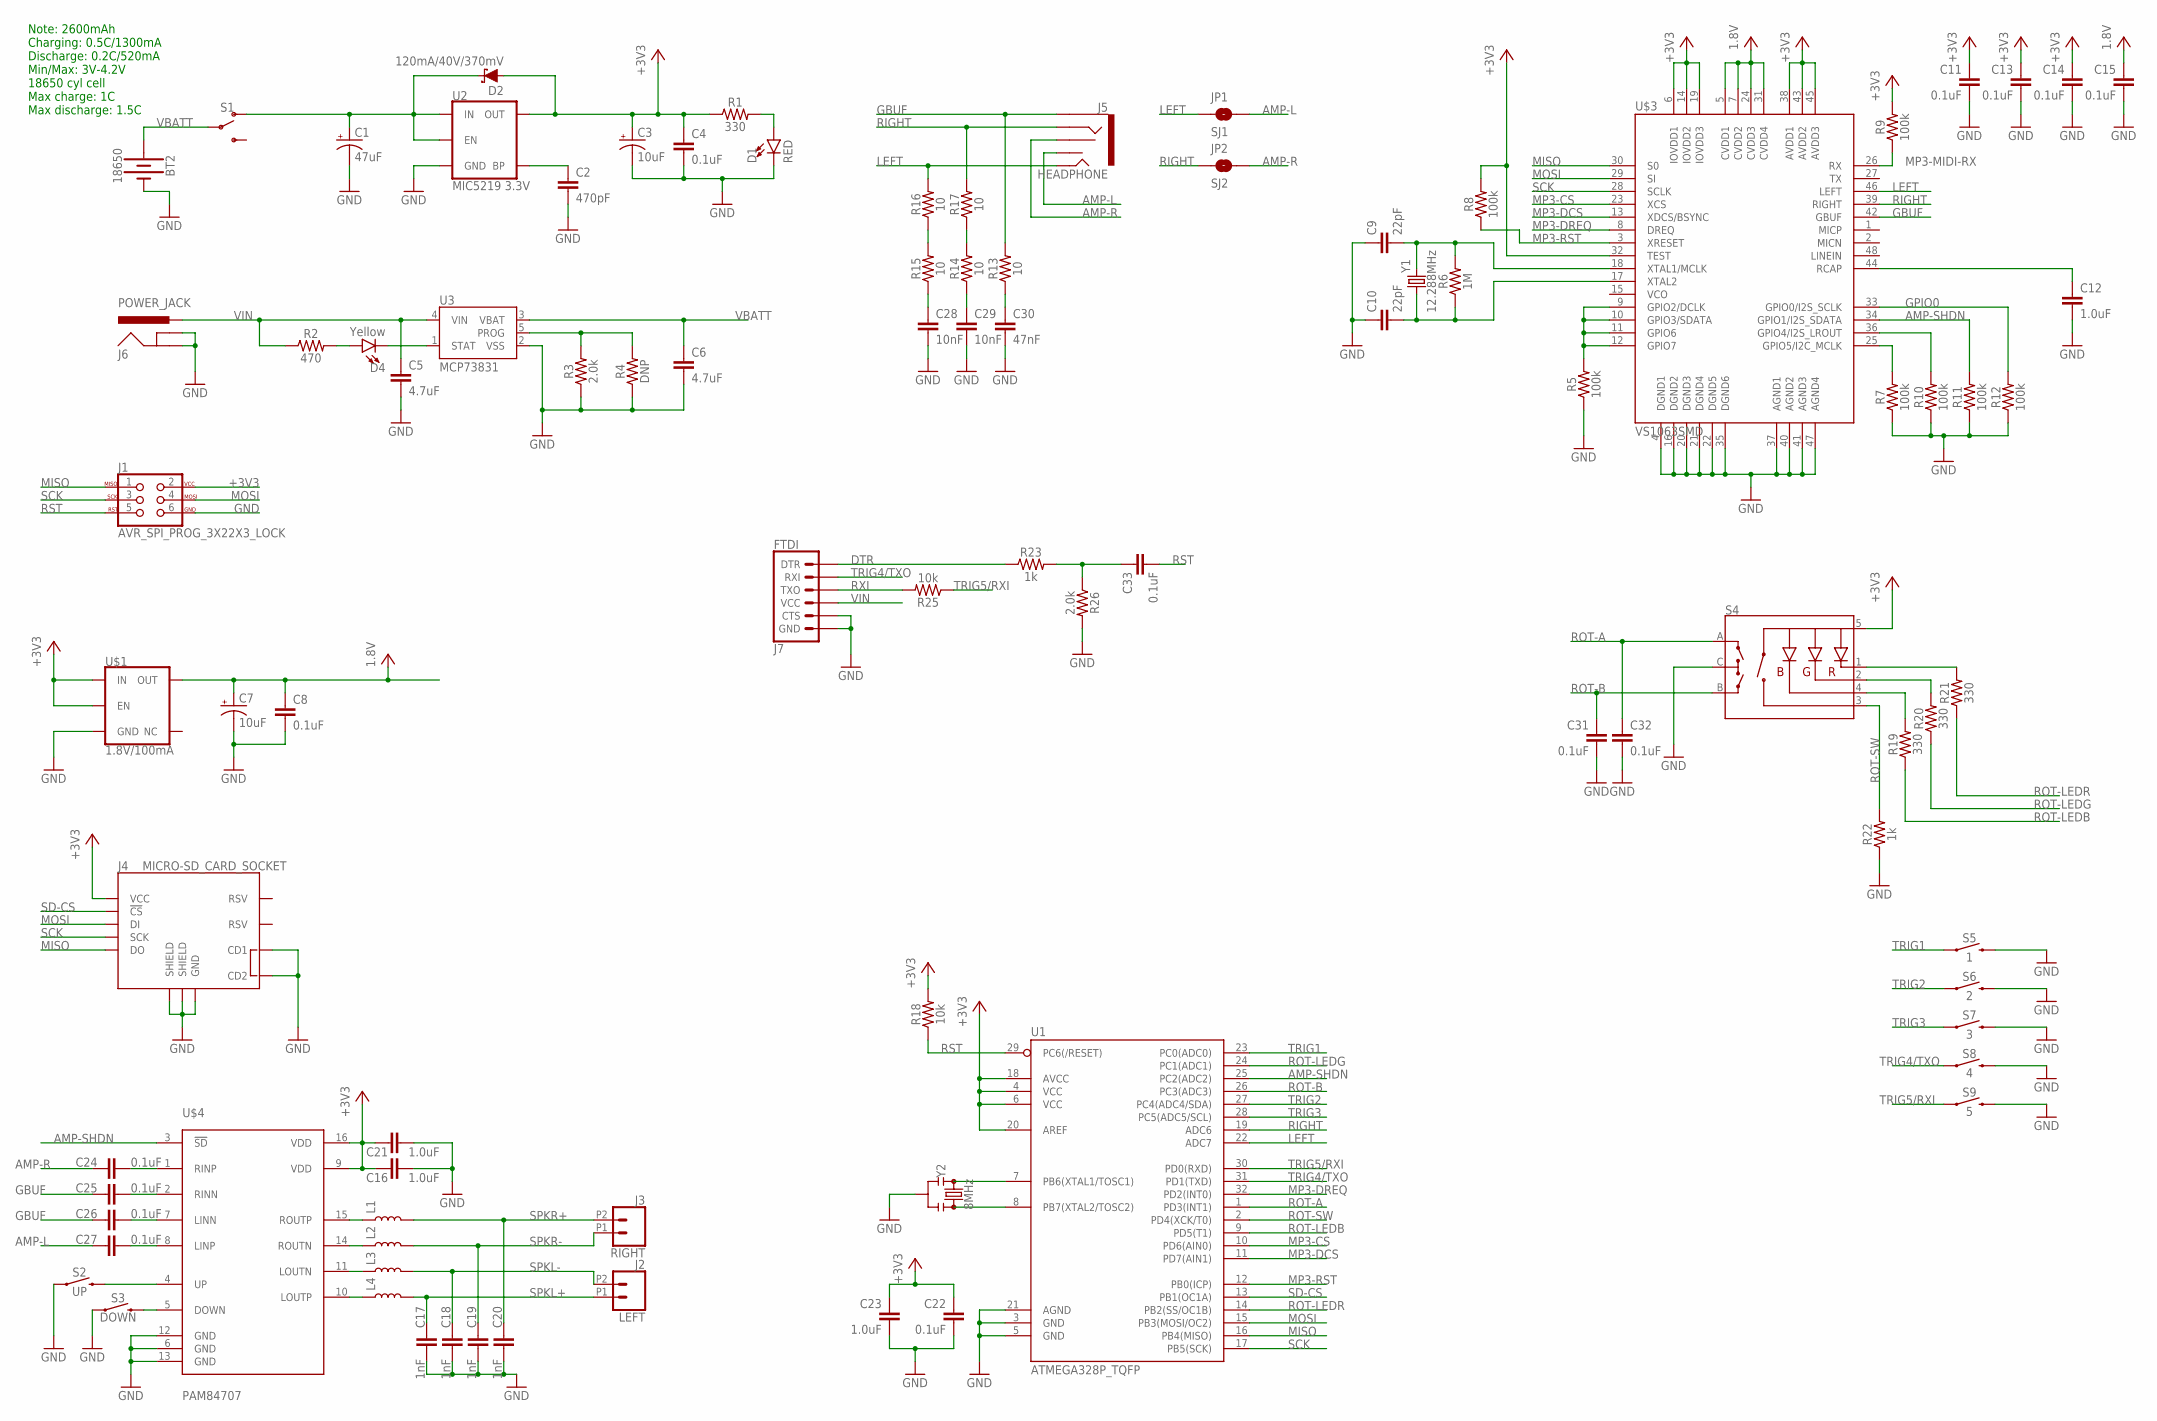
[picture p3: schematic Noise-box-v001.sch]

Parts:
BT2: 18650; BATTERY_18650-1043P
C1: 47uF; EIA3528
C2: 470pF; 0603
C3, C7: 10uF; EIA3216
C4, C8, C11, C13, C14, C15, C22, C24, C25, C26, C27, C31, C32, C33: 0.1uF; 0603
C5, C6: 4.7uF; 0603
C9, C10: 22pF; 0603
C12, C16, C21, C23: 1.0uF; 0603
C17, C18, C19, C20: 1nF; 0603
C28, C29: 10nF; 0603
C30: 47nF; 0603
D1: RED; LED-0603
D2: 120mA/40V/370mV; SOD-523
D4: Yellow; LED-0603
J1: AVR_SPI_PROG_3X22X3_LOCK; 2X3_LOCK
J2: LEFT; 1X02_2.54_SCREWTERM
J3: RIGHT; 1X02_2.54_SCREWTERM
J4: MICRO-SD_CARD_SOCKET; MICRO-SD-SOCKET
J5: HEADPHONE; AUDIO-JACK-3.5MM-SMD
J6: POWER_JACK; POWER_JACK_PTH
J7: FTDI; 6_PIN_SERIAL_TARGET_SIDE_W_SILK
JP1: SJ1; SMT-JUMPER_2_NO_SILK
JP2: SJ2; SMT-JUMPER_2_NO_SILK
L1, L2, L3, L4: INDUCTOR-0805-3.3UH; 0805
R1, R19, R20, R21: 330; 0603
R2: 470; 0603
R3, R26: 2.0k; 0603
R4: DNP; 0603
R5, R7, R8, R9, R10, R11, R12: 100k; 0603
R6: 1M; 0603
R13, R14, R15, R16, R17: 10; 0603
R18, R25: 10k; 0603
R22, R23: 1k; 0603
S1: SWITCH-SPDT-SMD-RIGHT-ANGLE; SWITCH_SPST_SMD_A
S2: UP; TACTILE_SWITCH_SMD_4.5MM
S3: DOWN; TACTILE_SWITCH_SMD_4.5MM
S4: ENCODER-RGB-SWITCH; ENCODER_LED_3
S5: 1; TACTILE_SWITCH_SMD_4.5MM
S6: 2; TACTILE_SWITCH_SMD_4.5MM
S7: 3; TACTILE_SWITCH_SMD_4.5MM
S8: 4; TACTILE_SWITCH_SMD_4.5MM
S9: 5; TACTILE_SWITCH_SMD_4.5MM
U1: ATMEGA328P_TQFP; TQFP32-08
U2: MIC5219 3.3V; SOT23-5
U3: MCP73831; SOT23-5
U$1: 1.8V/100mA; SC70
U$3: VS1063SMD; LQFP-48
U$4: PAM84707; SO16
Y1: 12.288MHz; CRYSTAL-SMD-5X3.2-4PAD
Y2: 8MHz; RESONATOR-SMD-3.2X1.3

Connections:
+3V3: C3.+, C4.1, C11.1, C13.1, C14.1, C16.1, C21.1, C22.1, C23.1, D2.A, J1.2, J4.VCC, R1.1, R8.2, R9.2, R18.2, S4.5 (+), U1.4 (VCC), U1.6 (VCC), U1.18 (AVCC), U1.20 (AREF), U2.5 (OUT), U$1.1 (IN), U$1.3 (EN), U$3.6 (IOVDD1), U$3.14 (IOVDD2), U$3.19 (IOVDD3), U$3.32 (TEST), U$3.38 (AVDD1), U$3.43 (AVDD2), U$3.45 (AVDD3), U$4.9 (VDD), U$4.16 (VDD)
AMP-L: C27.1, J5.TSH, JP1.2
AMP-R: C24.1, J5.RSH, JP2.2
AMP-SHDN: R11.2, U1.25 (PC2(ADC2)), U$3.34 (GPIO1/I2S_SDATA), U$4.3 (!SD)
DTR: J7.P$1 (DTR), R23.1
GBUF: C25.1, C26.1, J5.SLEEVE, R13.2, U$3.42 (GBUF)
GND: BT2.GND@1 (-), C1.C (-), C2.2, C3.-, C4.2, C5.2, C6.2, C7.-, C8.2, C9.1, C10.1, C11.2, C12.2, C13.2, C14.2, C15.2, C16.2, C17.2, C18.2, C19.2, C20.2, C21.2, C22.2, C23.2, C28.2, C29.2, C30.2, C31.2, C32.2, D1.C, J1.6, J4.CD1, J4.CD2, J4.GND, J4.GND1 (SHIELD), J4.GND3 (SHIELD), J6.GND, J6.GNDBREAK, J7.P$5 (CTS), J7.P$6 (GND), R3.1, R4.1, R5.1, R7.1, R10.1, R11.1, R12.1, R22.1, R26.2, S2.2 (1), S2.3 (1), S3.2 (1), S3.3 (1), S4.C, S5.1 (2), S5.4 (2), S6.1 (2), S6.4 (2), S7.1 (2), S7.4 (2), S8.1 (2), S8.4 (2), S9.1 (2), S9.4 (2), U1.3 (GND), U1.5 (GND), U1.21 (AGND), U2.2 (GND), U3.2 (VSS), U$1.2 (GND), U$3.4 (DGND1), U$3.16 (DGND2), U$3.20 (DGND3), U$3.21 (DGND4), U$3.22 (DGND5), U$3.35 (DGND6), U$3.37 (AGND1), U$3.40 (AGND2), U$3.41 (AGND3), U$3.47 (AGND4), U$4.6 (GND), U$4.12 (GND), U$4.13 (GND), Y2.2
GPIO0: R12.2, U$3.33 (GPIO0/I2S_SCLK)
LEFT: J5.TIP, JP1.1, R16.2, U1.22 (ADC7), U$3.46 (LEFT)
MISO: J1.1, J4.DO, U1.16 (PB4(MISO)), U$3.30 (S0)
MOSI: J1.4, J4.DI, U1.15 (PB3(MOSI/OC2)), U$3.29 (SI)
MP3-CS: U1.10 (PD6(AIN0)), U$3.23 (XCS)
MP3-DCS: U1.11 (PD7(AIN1)), U$3.13 (XDCS/BSYNC)
MP3-DREQ: U1.32 (PD2(INT0)), U$3.8 (DREQ)
MP3-MIDI-RX: R9.1, U$3.26 (RX)
MP3-RST: R8.1, U1.12 (PB0(ICP)), U$3.3 (XRESET)
unnamed: D4.A, R2.2
unnamed: C2.1, U2.4 (BP)
unnamed: D1.A, R1.2
unnamed: R3.2, R4.2, U3.5 (PROG)
unnamed: U1.7 (PB6(XTAL1/TOSC1)), Y2.1
unnamed: R5.2, U$3.9 (GPIO2/DCLK), U$3.10 (GPIO3/SDATA), U$3.11 (GPIO6), U$3.12 (GPIO7)
unnamed: D4.C, U3.1 (STAT)
unnamed: U1.8 (PB7(XTAL2/TOSC2)), Y2.3
unnamed: L1.1, U$4.15 (ROUTP)
unnamed: L2.1, U$4.14 (ROUTN)
unnamed: L3.1, U$4.11 (LOUTN)
unnamed: L4.1, U$4.10 (LOUTP)
unnamed: C28.1, R15.1
unnamed: R7.2, U$3.25 (GPIO5/I2C_MCLK)
unnamed: R10.2, U$3.36 (GPIO4/I2S_LROUT)
unnamed: C29.1, R14.1
unnamed: C9.2, R6.2, U$3.18 (XTAL1/MCLK), Y1.3 (2)
unnamed: C10.2, R6.1, U$3.17 (XTAL2), Y1.1
unnamed: C30.1, R13.1
unnamed: R15.2, R16.1
unnamed: C12.1, U$3.44 (RCAP)
unnamed: R14.2, R17.1
unnamed: C24.2, U$4.1 (RINP)
unnamed: C33.1, R23.2, R26.1
unnamed: R19.2, S4.4 (-B)
unnamed: R20.2, S4.2 (-G)
unnamed: R21.2, S4.1 (-R)
unnamed: C25.2, U$4.2 (RINN)
unnamed: C26.2, U$4.7 (LINN)
unnamed: C27.2, U$4.8 (LINP)
unnamed: S3.1 (2), S3.4 (2), U$4.5 (DOWN)
unnamed: S2.1 (2), S2.4 (2), U$4.4 (UP)
unnamed: C1.A (+), D2.C, S1.1 (O), U2.1 (IN), U2.3 (EN)
RIGHT: J5.RING, JP2.1, R17.2, U1.19 (ADC6), U$3.39 (RIGHT)
ROT-A: C32.1, S4.A, U1.1 (PD3(INT1))
ROT-B: C31.1, S4.B, U1.26 (PC3(ADC3))
ROT-LEDB: R19.1, U1.9 (PD5(T1))
ROT-LEDG: R20.1, U1.24 (PC1(ADC1))
ROT-LEDR: R21.1, U1.14 (PB2(SS/OC1B))
ROT-SW: R22.2, S4.3 (SW), U1.2 (PD4(XCK/T0))
RST: C33.2, J1.5, R18.1, U1.29 (PC6(/RESET))
RXI: J7.P$2 (TXO), R25.2
SCK: J1.3, J4.SCLK (SCK), U1.17 (PB5(SCK)), U$3.28 (SCLK)
SD-CS: J4.CS (!CS), U1.13 (PB1(OC1A))
SPKL+: C17.1, J2.P1 (1), L4.2
SPKL-: C18.1, J2.P2 (2), L3.2
SPKR+: C20.1, J3.P2 (2), L1.2
SPKR-: C19.1, J3.P1 (1), L2.2
TRIG1: S5.2 (1), S5.3 (1), U1.23 (PC0(ADC0))
TRIG2: S6.2 (1), S6.3 (1), U1.27 (PC4(ADC4/SDA))
TRIG3: S7.2 (1), S7.3 (1), U1.28 (PC5(ADC5/SCL))
TRIG4/TXO: J7.P$3 (RXI), S8.2 (1), S8.3 (1), U1.31 (PD1(TXD))
TRIG5/RXI: R25.1, S9.2 (1), S9.3 (1), U1.30 (PD0(RXD))
VBATT: BT2.PWR@1 (+), C6.1, S1.2, U3.3 (VBAT)
VCC: C7.+, C8.1, C15.1, U$1.5 (OUT), U$3.5 (CVDD1), U$3.7 (CVDD2), U$3.24 (CVDD3), U$3.31 (CVDD4)
VIN: C5.1, J6.PWR, J7.P$4 (VCC), R2.1, U3.4 (VIN)

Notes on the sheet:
Note: 2600mAh Charging: 0.5C/1300mA Discharge: 0.2C/520mA Min/Max: 3V-4.2V 18650 cyl cell Max charge: 1C Max discharge: 1.5C

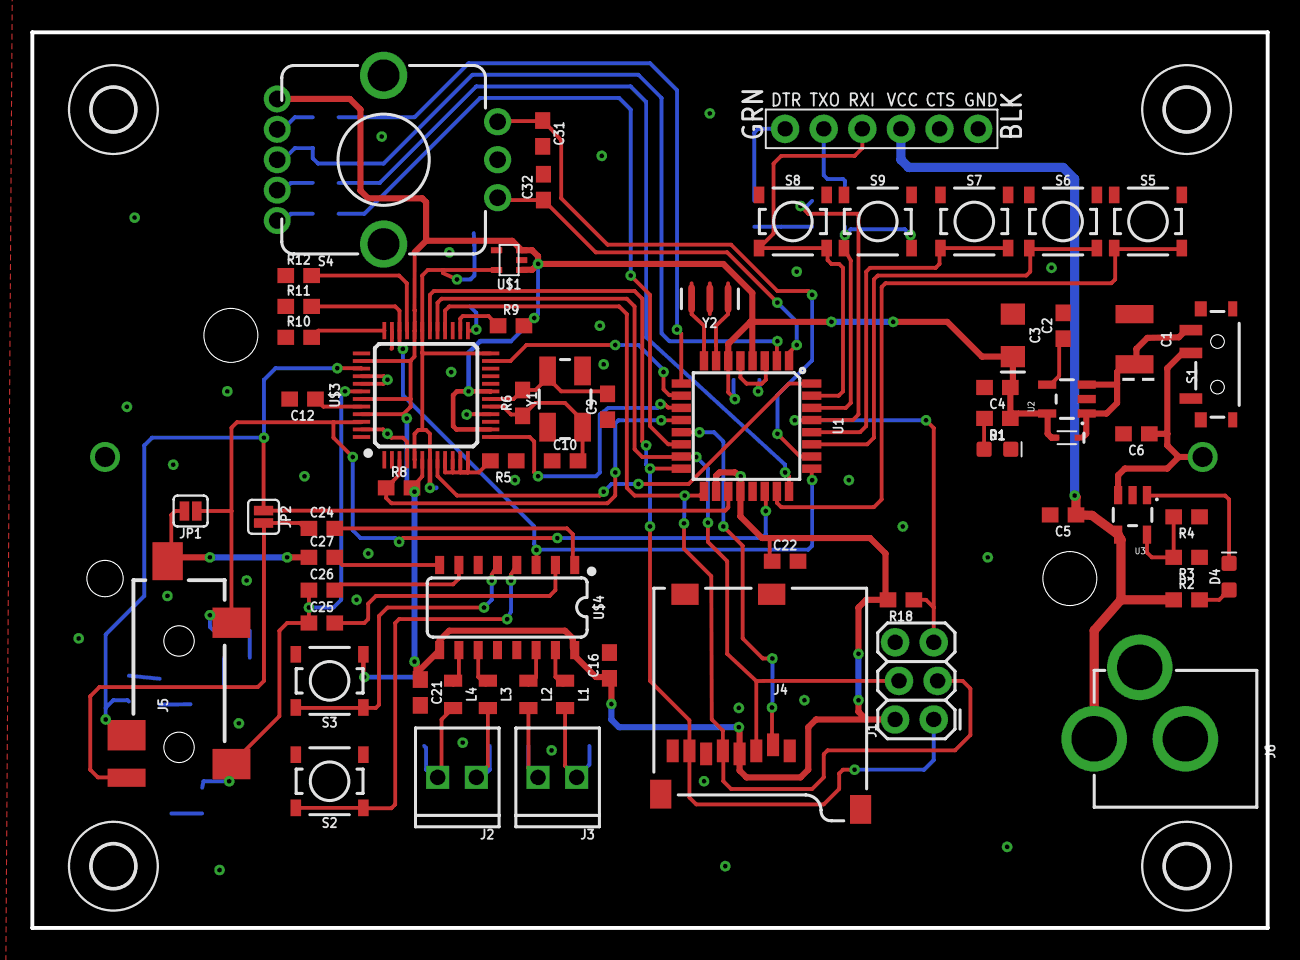
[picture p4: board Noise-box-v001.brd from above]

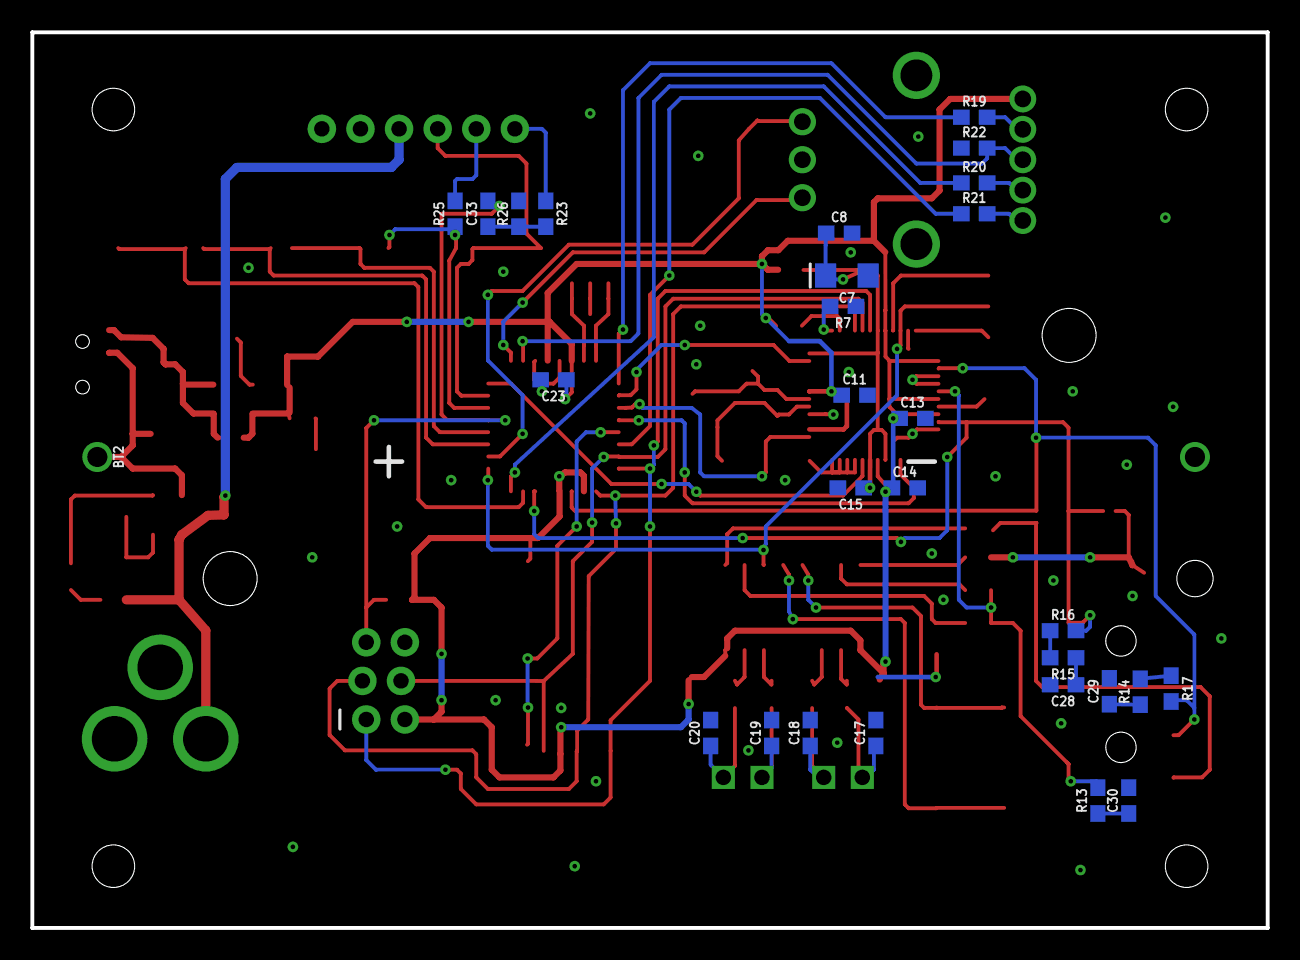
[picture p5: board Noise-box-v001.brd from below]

Board: 2 copper layers, 81.3 x 58.9 mm, 96 parts (29 on the bottom side), 72 nets.

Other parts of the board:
U$2, U$5, U$6, U$7: 2,8

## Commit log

2017-02-08 Project Setup
    Started project files. Included outline, sch, brd, pdf's for part
    research
    [Noise-box-v001.brd, Noise-box-v001.sch]
2017-02-10 Sch update - power
    Added voltage regulators and supporting components.
    [Noise-box-v001.brd, Noise-box-v001.sch]
2017-02-16 Schematic work
    Added regulator, battery charging circuit
    [Noise-box-v001.brd, Noise-box-v001.sch]
2017-02-16 Low voltage rail
    Added 1.8V rail to accomodate codec IC core
    [Noise-box-v001.brd, Noise-box-v001.sch]
2017-02-16 micro sd
    Added micro sd socket, to hold music tracks
    [Noise-box-v001.brd, Noise-box-v001.sch]
2017-02-17 mp3 decoder
    Added VL1063 codec, headphone jack
    [Noise-box-v001.brd, Noise-box-v001.sch]
2017-02-17 clk
    Added crystal for vs1063
    [Noise-box-v001.brd, Noise-box-v001.sch]
2017-02-17 vs1063
    Added all support circuitry to vs1063, including extra locations for cap
    filtering
    [Noise-box-v001.brd, Noise-box-v001.sch]
2017-02-17 Audio amp
    Added simple audio amplifier
    [Noise-box-v001.brd, Noise-box-v001.sch]
2017-02-20 Battery
    Picked battery with best available Wh/dollar
    [Battery Research.xlsx, Noise-box-v001.brd, Noise-box-v001.sch]
2017-02-20 Capacitor sizes
    research linear regulator capacitor sizing
2017-02-21 Layout
    First pass at layout. Established rough board dimensions. It seems that
    establishing GND different than Battery (-) will necessitate a long
    trace through the middle of the board. This might be avoided by going
    with a wire lead version of the battery holder and avoiding that
    unwanted trace by use of wires.
    [Noise-box-v001.brd, Noise-box-v001.sch]
2017-02-21 img
    Changed picture dir to "img". Added schematic image
2017-02-24 Layout updates
    Adjusted battery holder package. Began layout, establishing rough
    dimensions of the board.
    [Noise-box-v001.brd, Noise-box-v001.sch]
2017-02-25 Layout
    continued layout design. updated a few minor schematic errors
    [Noise-box-v001.brd, Noise-box-v001.sch]
2017-02-25 Triggers
    Added momentary buttons to act as triggers. These will choose between
    music categories, songs, or other user input features.
    [Noise-box-v001.brd, Noise-box-v001.sch]
2017-03-03 More layout, buttons, debug header
    Added a handful of buttons and a rotary switch to handle user inputs
    such a track selection, volume knob, pause/play, etc. Added 5 pin debug
    header for FTDI to USB adapter I have. Advanced the layout - nearly
    complete.
    [Noise-box-v001.brd, Noise-box-v001.sch]
2017-03-03 Updated images
    Added a new image of the layout and schematic
2017-03-03 Image
    Corrected schematic image file type
2017-03-03 Readme update
    Added a bit of formatting. Continued the explanation of the project.
    [Noise-box-v001.brd, Noise-box-v001.sch]
2017-03-03 Layout
    Further layout
    [Noise-box-v001.brd]
2017-03-04 Layout, CAM, BoM, Datasheets
    Finished layout, generated CAM files for manufacturing, generated BoM.
    Added several datasheets for reference
    [Noise-box-v001.brd, Noise-box-v001.sch]

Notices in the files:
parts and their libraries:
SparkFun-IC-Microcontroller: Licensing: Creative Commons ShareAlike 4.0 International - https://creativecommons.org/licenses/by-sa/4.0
